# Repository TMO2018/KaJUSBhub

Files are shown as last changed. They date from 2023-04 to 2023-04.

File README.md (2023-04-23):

# KaJUSBhub
USB-Adapter zum Einbau in ein C64-Gehäuse für die C64-Tastatur und -Joysticks zum Anschluss an den MiSTer

Auf der Platine enthalten sind:

- ein USB-Adapter dür die C64-Tastatur und -9-pol. Joystcks
- der USB-Hub des MiSTers
- eine über Feinsicherungen abgesicherte Stromversorgung für den MiSter, USB-Adapter und USB-Hub

Die Spannungsversorgung erfolgt mit einem C64-Netzteil.

Rev 0.1:
Version mit einem gemeinsamen Mikrocontroller PIC18F4550 für C64-Tastatur und -Joysticks

Rev 0.2:
Version mit seperaten Mikrocontrollern PIC18F4550 für C64-Tastatur und -Joysticks

Die Firmware basiert auf dem Projekt C64 VICE front-end von Simon Inns.
https://www.waitingforfriday.com/?p=470

IMG_Rev_0 1

Rev 0.1

Hinweis: In den Schaltplänen der Versionen 0.1 und 0.2 ist der Mikrokontroller mit PIC18F4450 beschriftet. Richtig ist aber PIC18F4550. Beide Mikrokontroller sind pin-kompatibel.

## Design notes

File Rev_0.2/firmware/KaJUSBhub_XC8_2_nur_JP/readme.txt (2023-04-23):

Versionen IDE und Compiler

MBLAB X 5.15 XC8 2.05

27.03.2019 
Keymapping auf dem MISTer C64-Core angepasst

24.06.2021
MBLAB X 5.50 XC8 2.32

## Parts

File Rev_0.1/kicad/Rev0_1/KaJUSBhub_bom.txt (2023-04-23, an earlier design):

Reference, Quantity, Value, Footprint, Datasheet
C1 C2 C5 C6 ,4,"220nF","Capacitors_SMD:C_0805_HandSoldering",""
C10 C11 C13 C15 C17 C18 C19 C20 C21 C22 ,10,"10uF","Capacitors_SMD:C_0805_HandSoldering",""
C12 ,1,"0.1uF","Capacitors_SMD:C_0805_HandSoldering",""
C14 C16 ,2,"0,1uF","Capacitors_SMD:C_0805_HandSoldering",""
C3 C4 ,2,"15pF","Capacitors_SMD:C_0805_HandSoldering",""
C7 C8 ,2,"100nF","Capacitors_SMD:C_0805_HandSoldering",""
C9 ,1,"470nF","Capacitors_SMD:C_0805_HandSoldering",""
F1 ,1,"0,5A flink","Fuse_Holders_and_Fuses:Fuseholder5x20_horiz_open_inline_Type-I",""
F2 ,1,"1,0A flink","Fuse_Holders_and_Fuses:Fuseholder5x20_horiz_open_inline_Type-I",""
F3 ,1,"2,0A träge","Fuse_Holders_and_Fuses:Fuseholder5x20_horiz_open_inline_Type-I",""
J1 ,1,"DIN-7","TMO:din-7",""
J2 ,1,"Versorgung MISTer","Connectors_Molex:Molex_KK-6410-02_02x2.54mm_Straight","~"
J3 ,1,"ICSP","Pin_Headers:Pin_Header_Straight_1x06_Pitch2.54mm",""
J4 ,1,"Joystick Port 1","Connectors_DSub:DSUB-9_Male_Horizontal_Pitch2.77x2.84mm_EdgePinOffset7.70mm_Housed_MountingHolesOffset9.12mm",""
J5 ,1,"Status-LED","TMO:Pin_Header_Straight_1x03_Pitch2.54mm_long_pad",""
J6 ,1,"Joystick Port 2","Connectors_DSub:DSUB-9_Male_Horizontal_Pitch2.77x2.84mm_EdgePinOffset7.70mm_Housed_MountingHolesOffset9.12mm",""
J7 ,1,"C64 Keyboard","TMO:Pin_Header_Straight_1x20_Pitch2.54mm_long_pad",""
LED1 LED11 LED13 LED3 LED5 LED7 LED9 ,7,"green","LEDs:LED_0805_HandSoldering",""
LED15 ,1,"red","LEDs:LED_0805_HandSoldering",""
LED10 LED12 LED14 LED2 LED4 LED6 LED8 ,7,"amber","LEDs:LED_0805_HandSoldering",""
MH1 MH2 MH3 MH4 MH5 ,5,"Conn_01x01","Mounting_Holes:MountingHole_3.7mm",""
P1 ,1,"USB IN","TMO:Pin_Header_Straight_1x04_Pitch2.54mm_long_pad",""
R1 R18 R2 R3 R4 ,5,"100k","Resistors_SMD:R_0805_HandSoldering",""
R10 R11 R12 R13 R14 R15 R16 R9 ,8,"510","Resistors_SMD:R_0805_HandSoldering",""
R17 ,1,"47k","Resistors_SMD:R_0805_HandSoldering",""
R19 ,1,"2k7","Resistors_SMD:R_0805_HandSoldering",""
R6 ,1,"1k","Resistors_SMD:R_0805_HandSoldering",""
R7 ,1,"150","Resistors_SMD:R_0805_HandSoldering",""
R5 R8 ,2,"10k","Resistors_SMD:R_0805_HandSoldering",""
SW1 ,1,"DPDT_SWITCH","TMO:DPDT_SWITCH",""
U1 ,1,"PIC18F4450-IP","Housings_DIP:DIP-40_W15.24mm_Socket_LongPads",""
U2 ,1,"24C02","Housings_SOIC:SOIC-8_3.9x4.9mm_Pitch1.27mm",""
U3 ,1,"FE2.1-48","Housings_QFP:LQFP-48_7x7mm_Pitch0.5mm",""
USB1 USB2 USB3 ,3,"USB_A","Connectors:USB_A",""
USB5 USB6 ,2,"USB out","TMO:Pin_Header_Straight_1x04_Pitch2.54mm_long_pad",""
USB7 ,1,"USB out","Pin_Headers:Pin_Header_Straight_1x04_Pitch2.54mm",""
X1 ,1,"20MHz","Crystals:Crystal_SMD_5032-2pin_5.0x3.2mm_HandSoldering",""
X2 ,1,"12MHz","Crystals:Crystal_SMD_5032-2pin_5.0x3.2mm_HandSoldering",""

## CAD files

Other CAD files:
Rev_0.1/firmware/KaJUSBhub_XC8_1/KaJUSBhub.X/dist/default/production/KaJUSBhub.X.production.obj

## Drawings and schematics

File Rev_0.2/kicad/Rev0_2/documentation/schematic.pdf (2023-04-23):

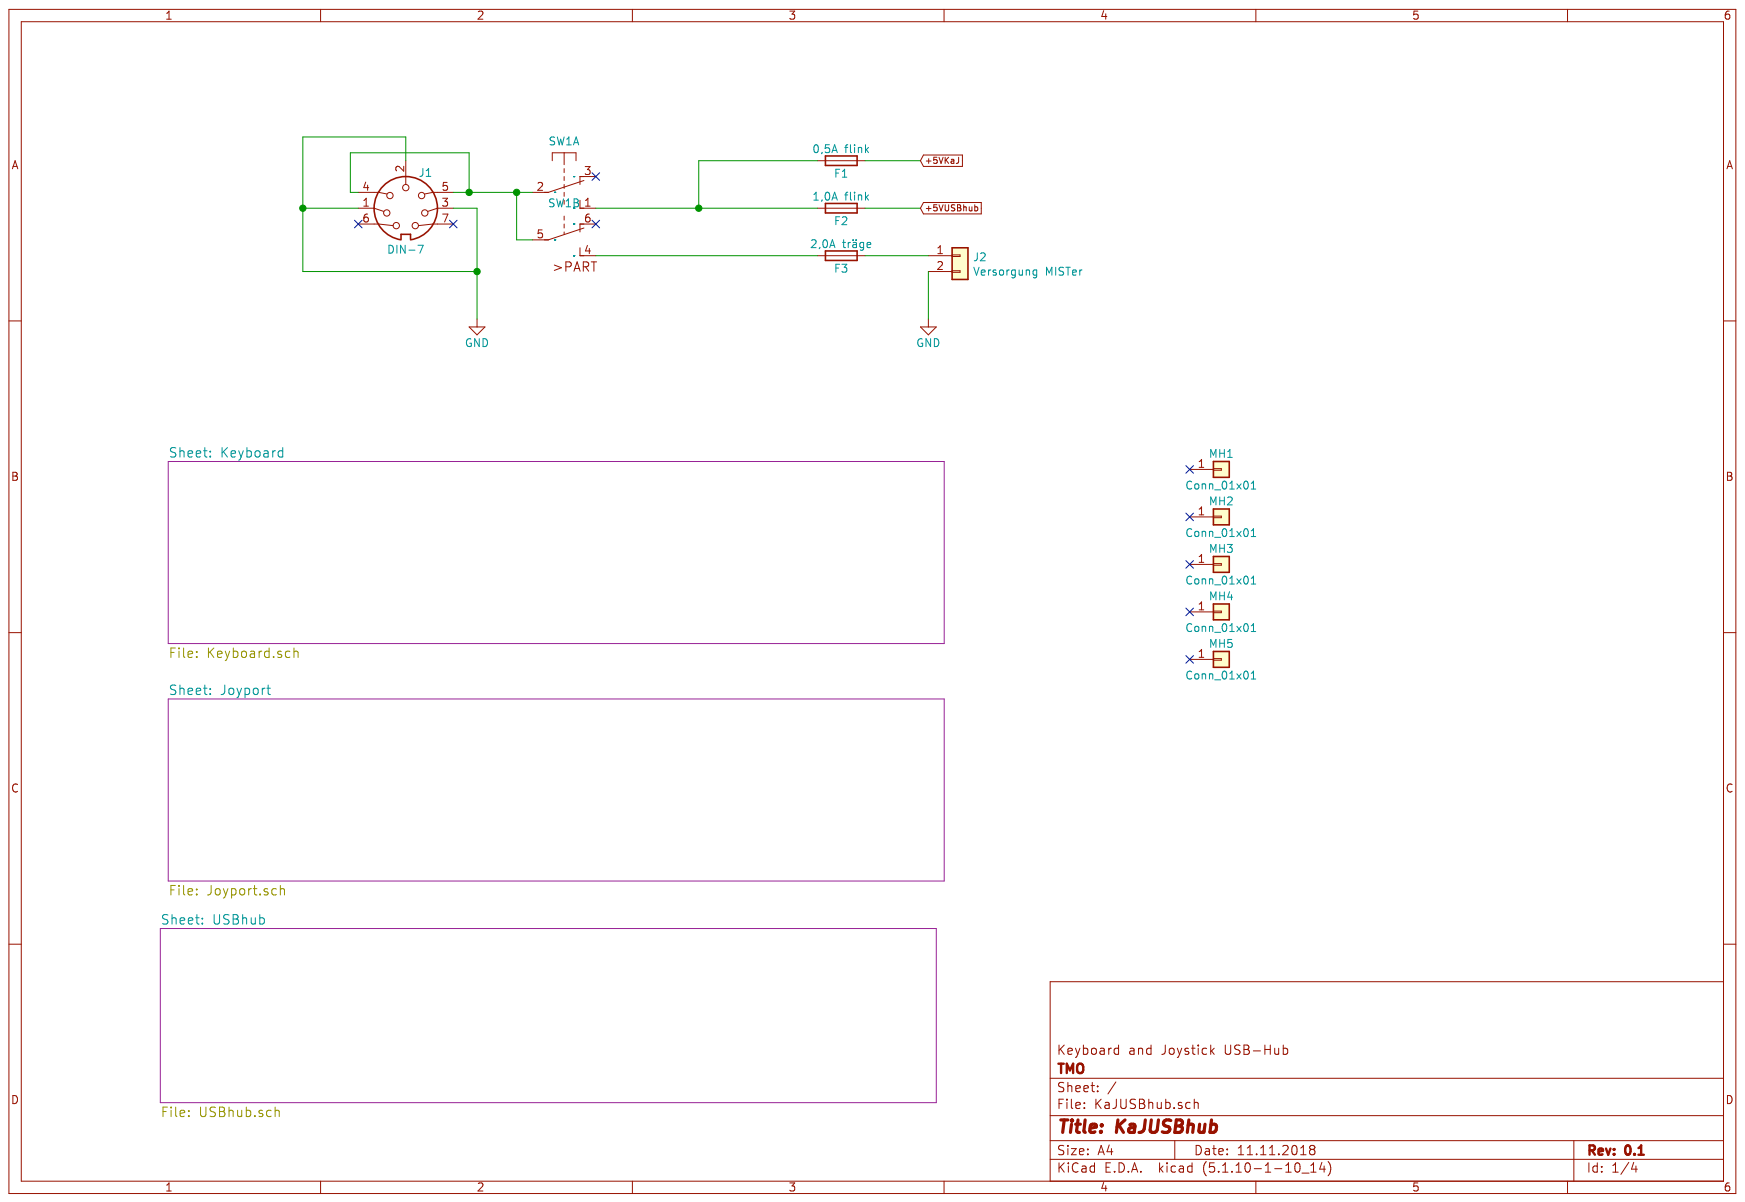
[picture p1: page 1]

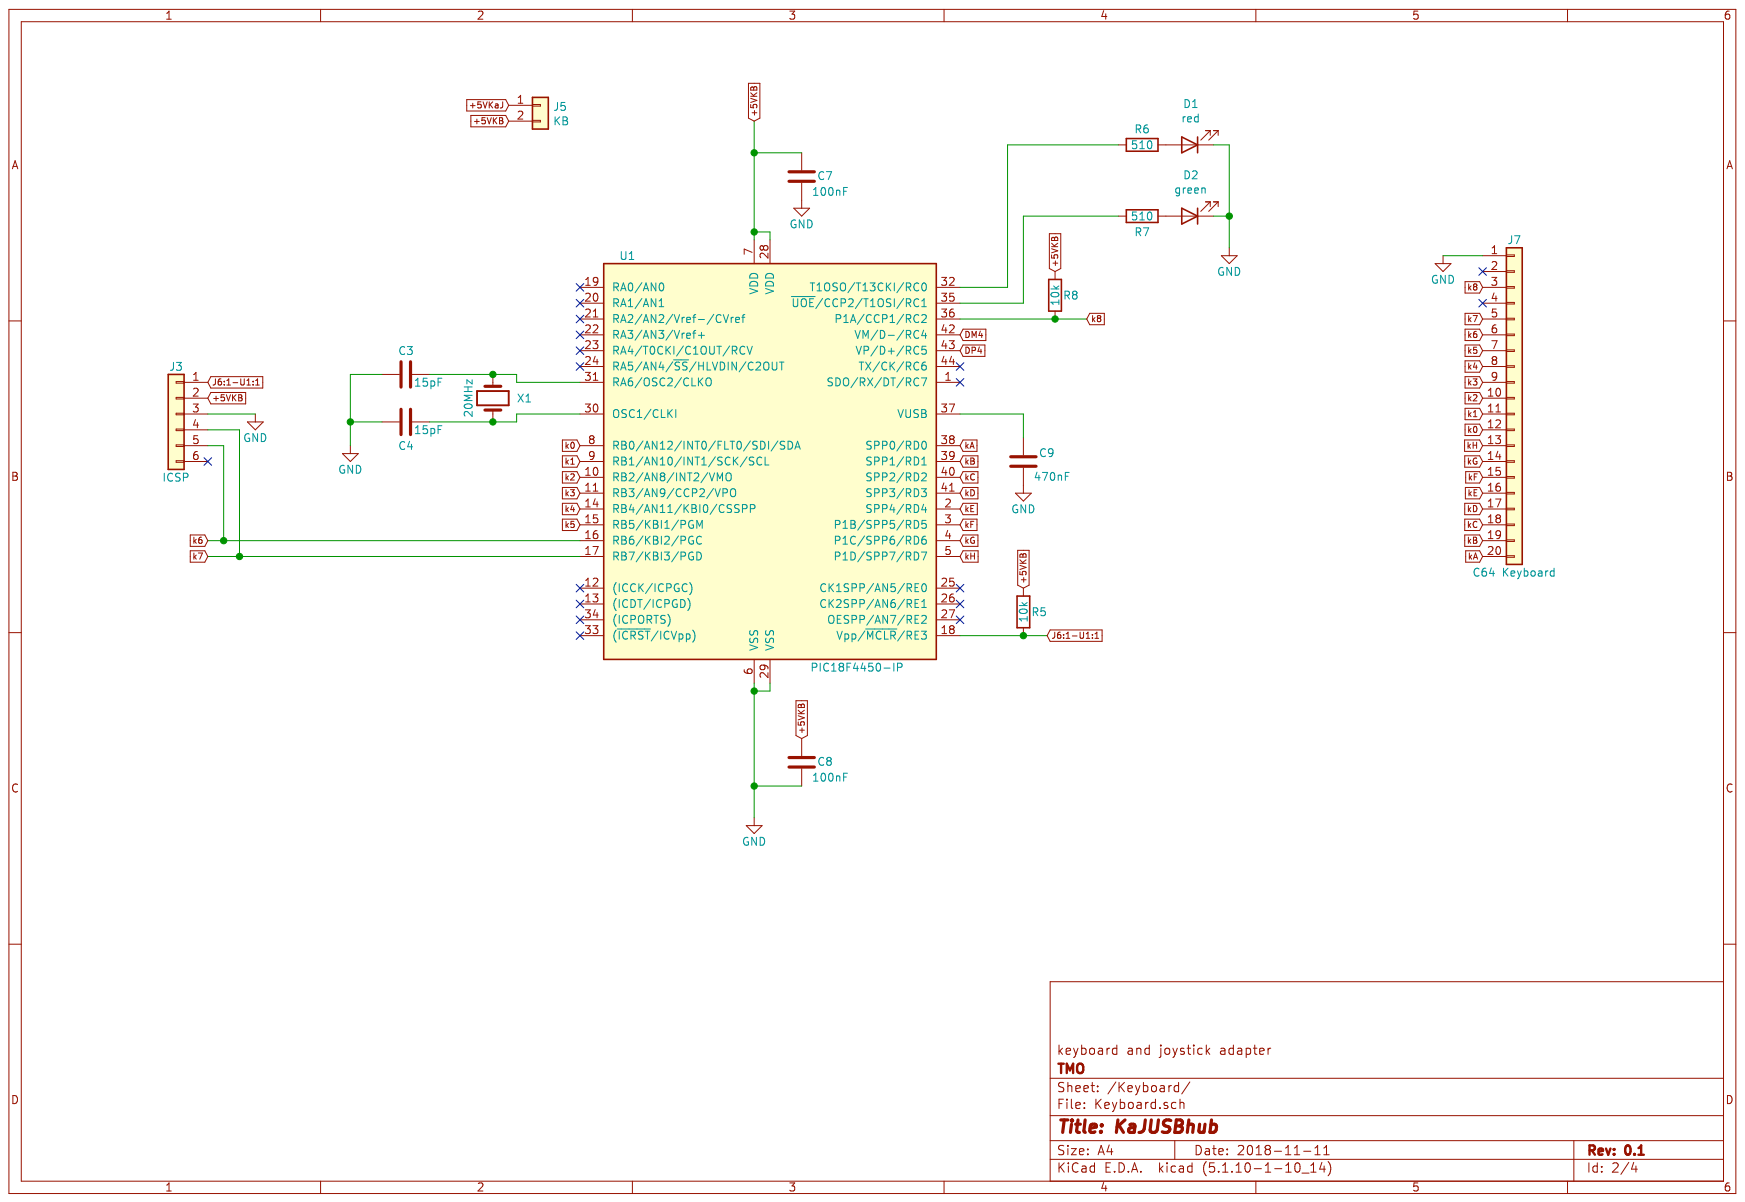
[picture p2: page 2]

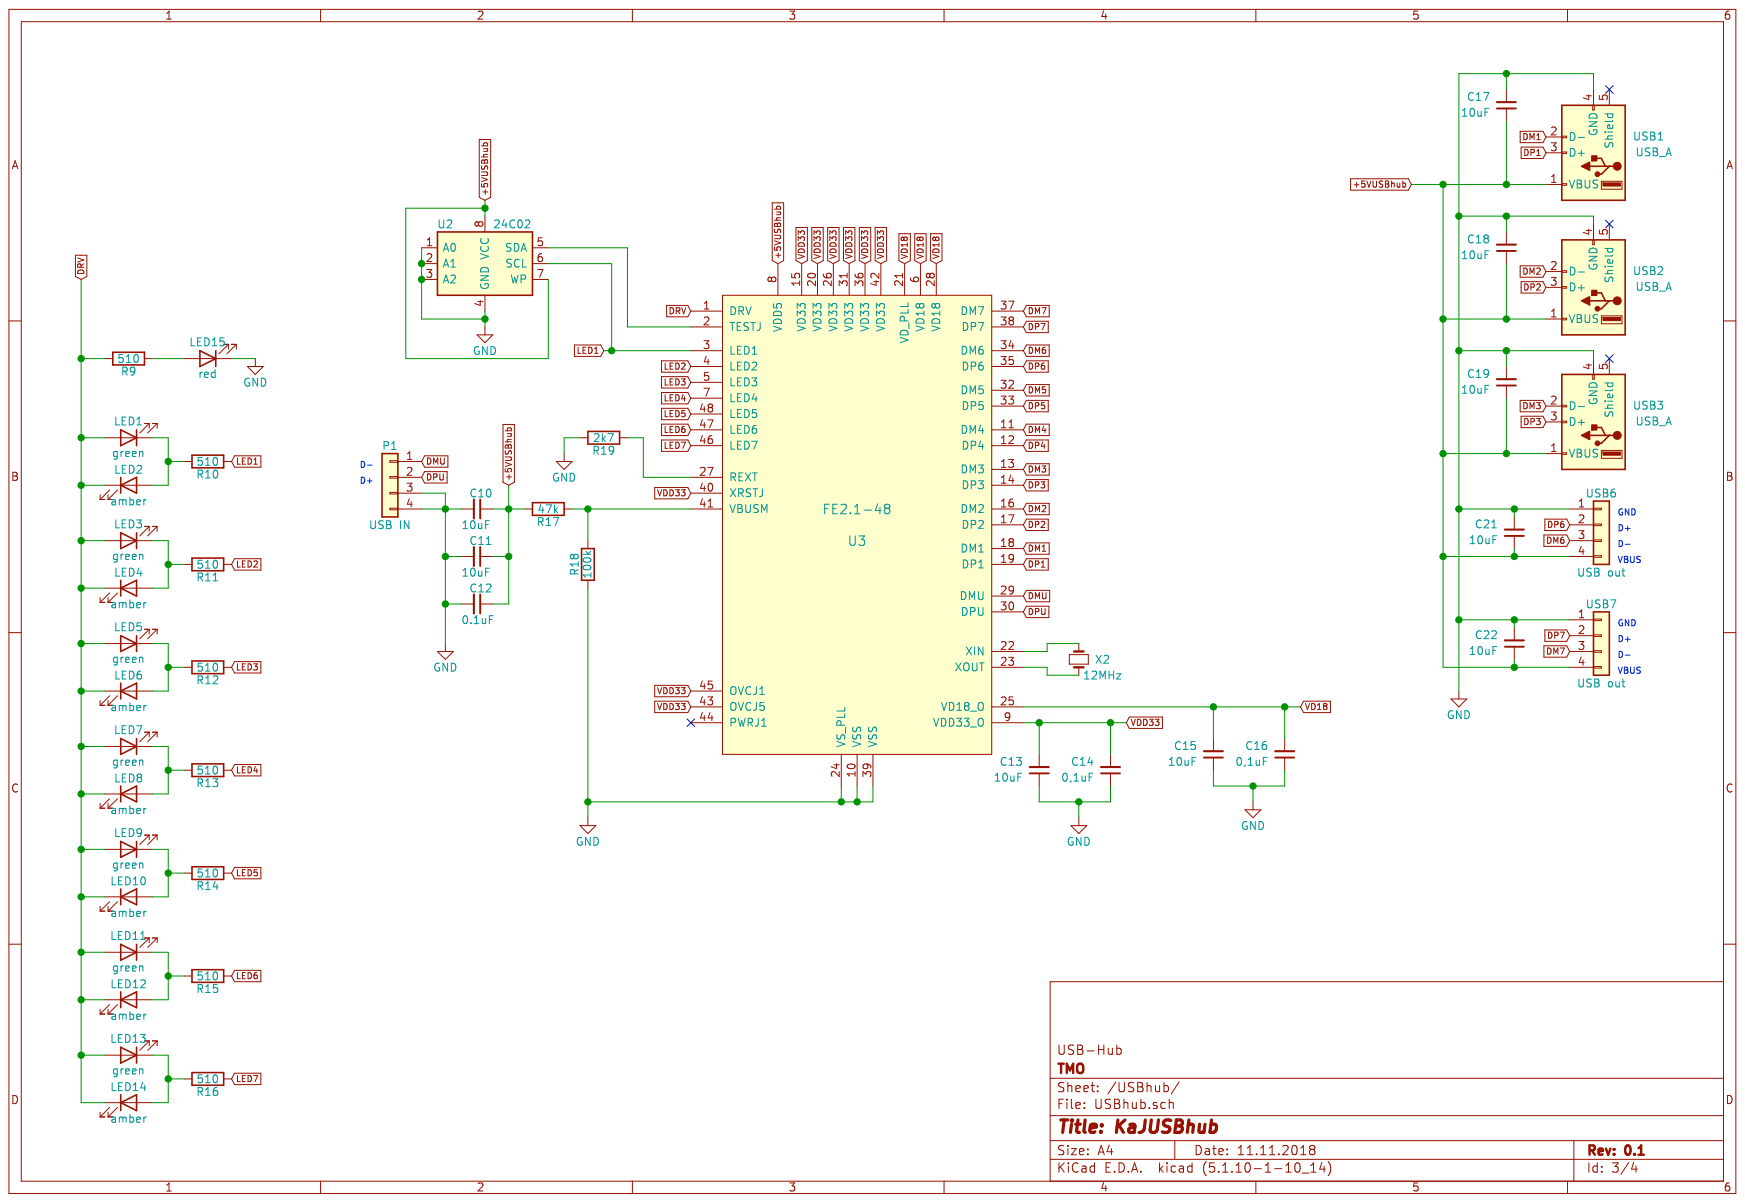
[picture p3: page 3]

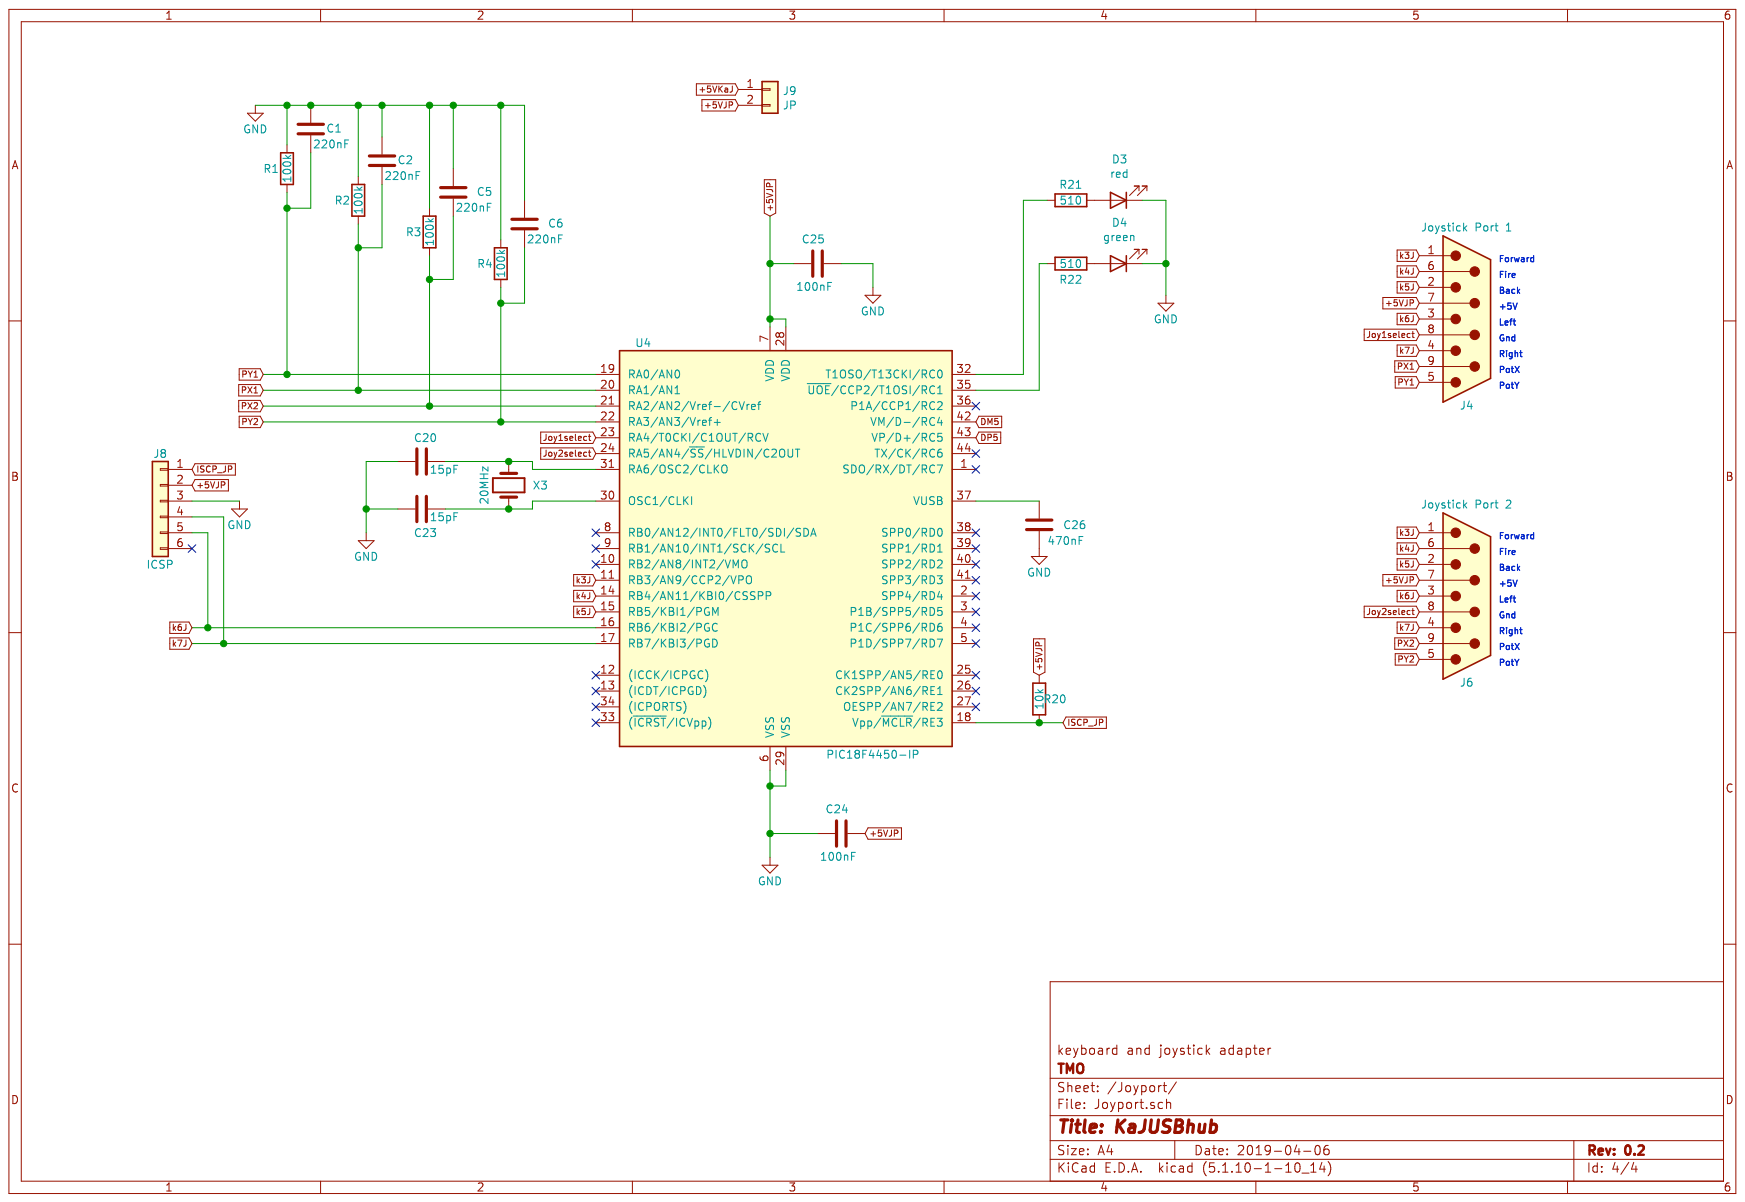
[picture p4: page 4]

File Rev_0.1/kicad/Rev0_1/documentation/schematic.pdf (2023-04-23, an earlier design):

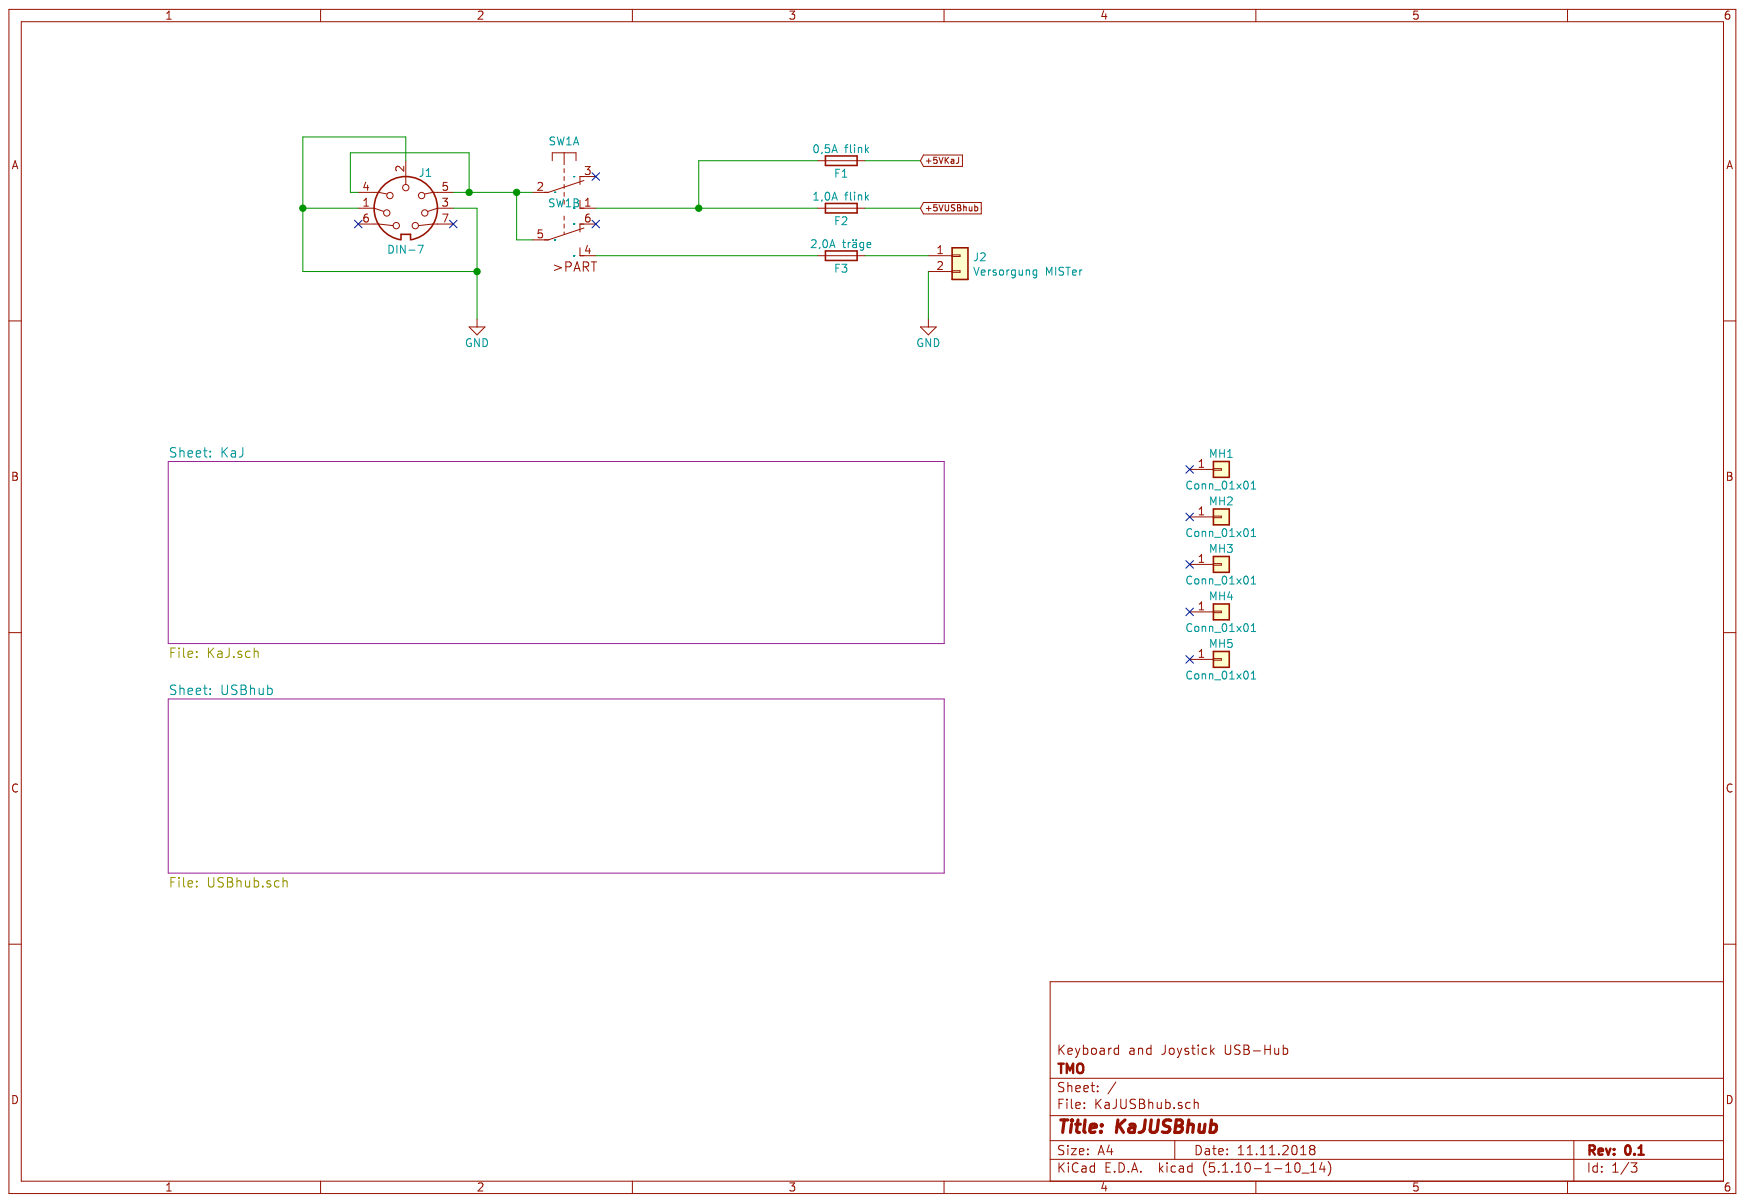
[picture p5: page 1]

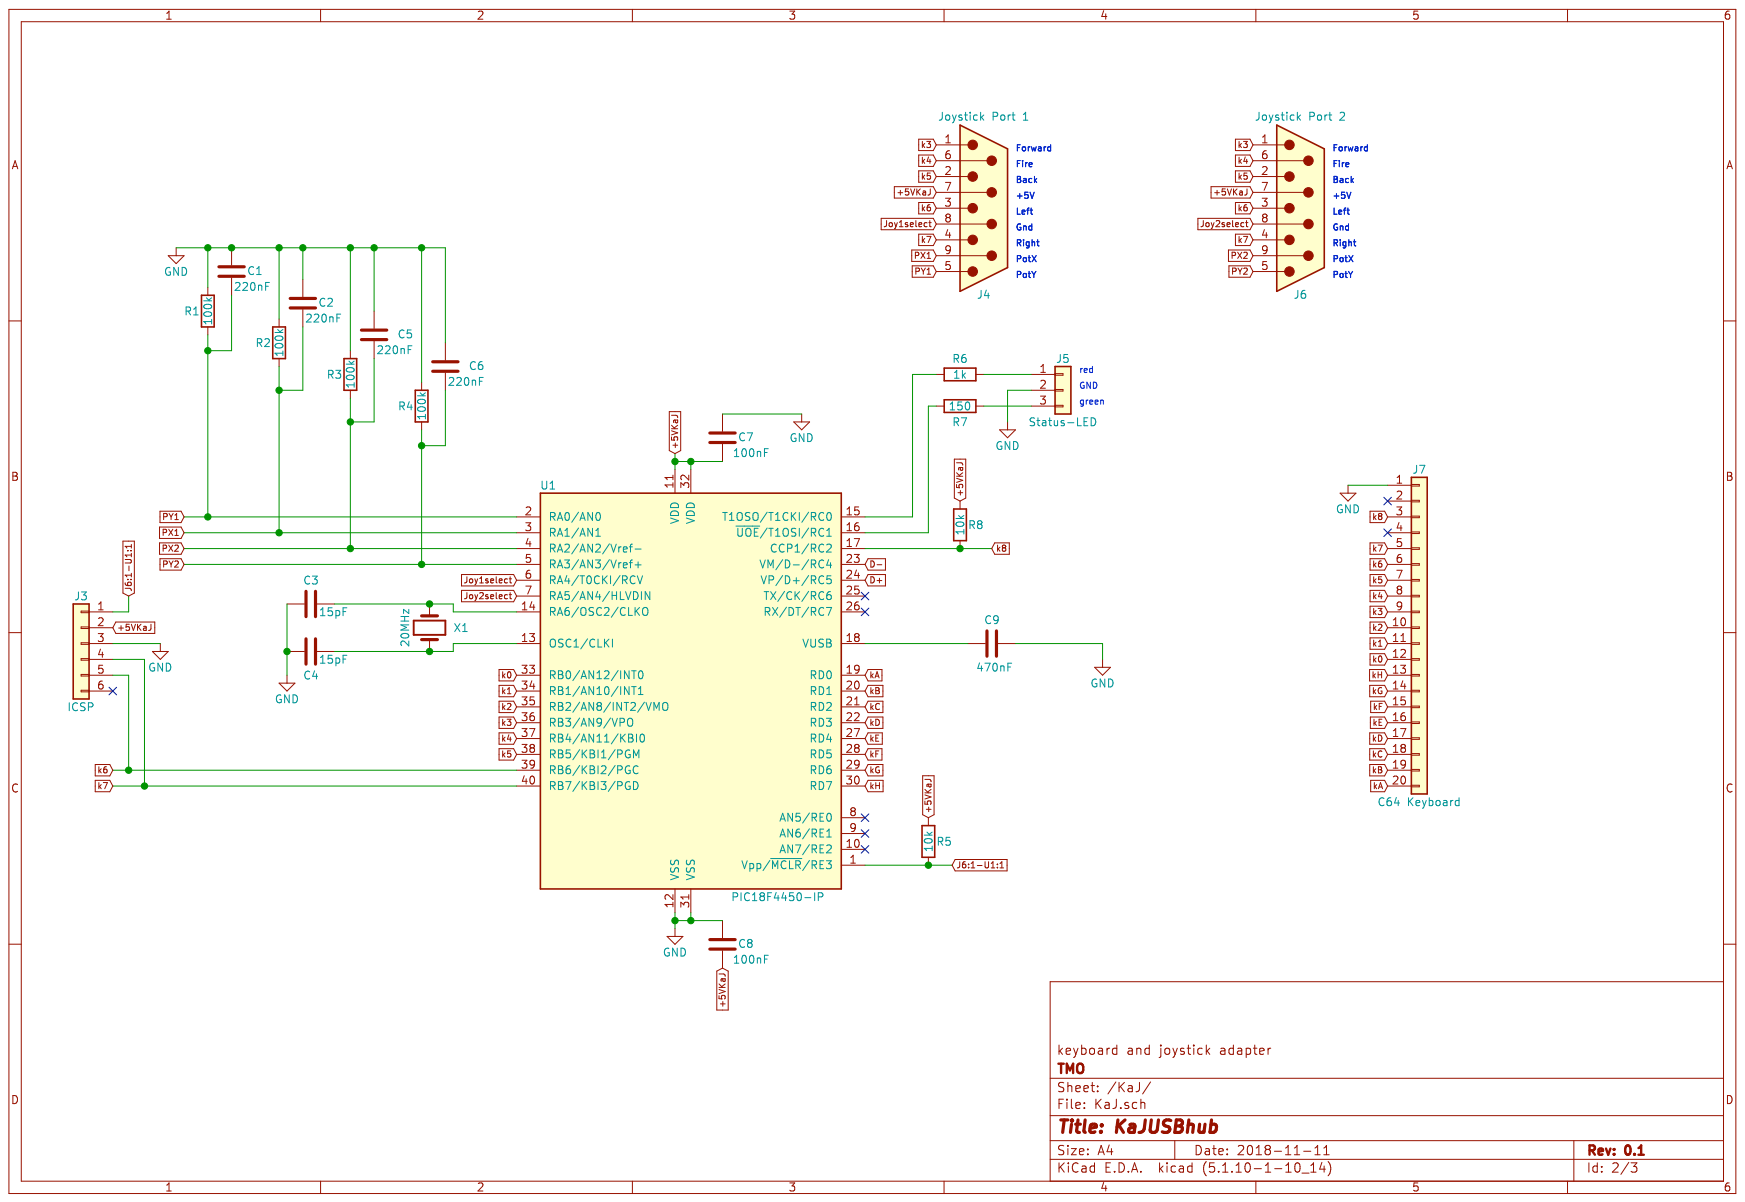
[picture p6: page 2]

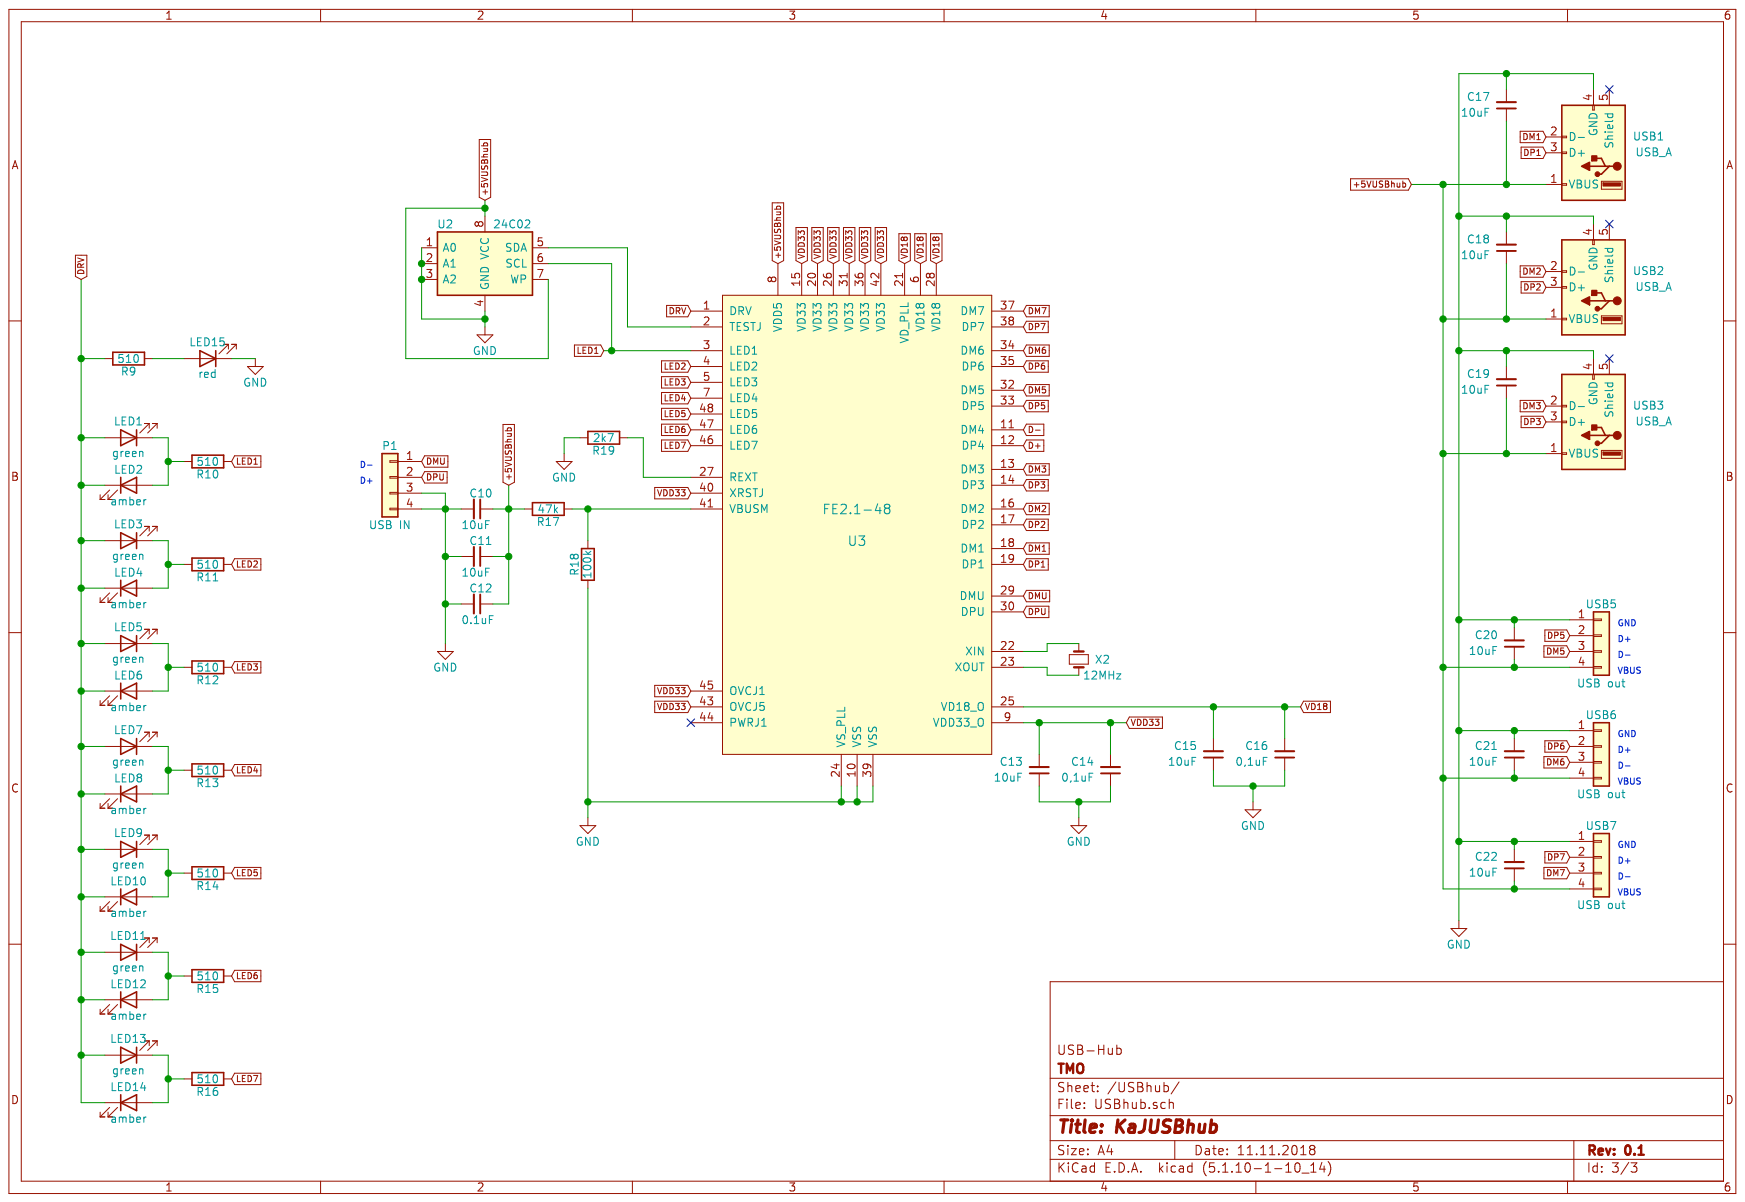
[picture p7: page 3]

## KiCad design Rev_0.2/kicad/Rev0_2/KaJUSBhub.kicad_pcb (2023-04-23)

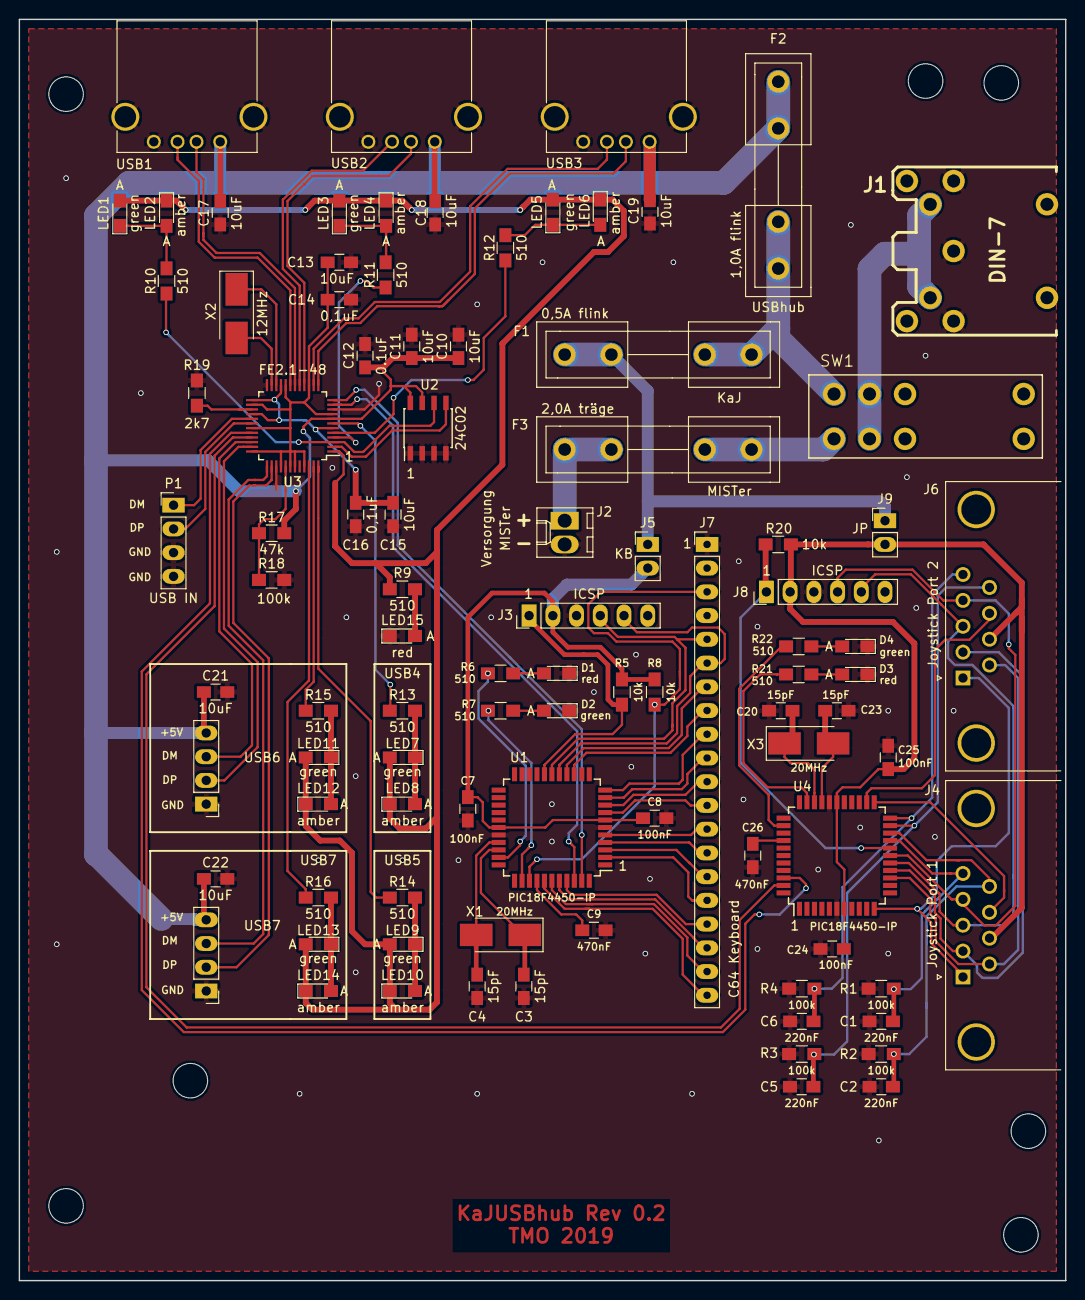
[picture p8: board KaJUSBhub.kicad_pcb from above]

Board: 2 copper layers, 112.0 x 135.0 mm, 98 parts (0 on the bottom side), 92 nets.

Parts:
C1, C2, C5, C6: 220nF; C_0805_HandSoldering
C3, C4, C20, C23: 15pF; C_0805_HandSoldering
C7, C8, C24, C25: 100nF; C_0805_HandSoldering
C9, C26: 470nF; C_0805_HandSoldering
C10, C11, C13, C15, C17, C18, C19, C21, C22: 10uF; C_0805_HandSoldering
C12: 0.1uF; C_0805_HandSoldering
C14, C16: 0,1uF; C_0805_HandSoldering
D1, D3: red; LED_0805_HandSoldering
D2, D4: green; LED_0805_HandSoldering
F1: 0,5A flink; Fuseholder5x20_horiz_open_inline_Type-I
F2: 1,0A flink; Fuseholder5x20_horiz_open_inline_Type-I
F3: 2,0A träge; Fuseholder5x20_horiz_open_inline_Type-I
J1: DIN-7; din-7
J2: Versorgung MISTer; Molex_KK-6410-02_02x2.54mm_Straight
J3, J8: ICSP; Pin_Header_Straight_1x06_Pitch2.54mm
J4: Joystick Port 1; DSUB-9_Male_Horizontal_Pitch2.77x2.84mm_EdgePinOffset7.70mm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
J5: KB; Pin_Header_Straight_1x02_Pitch2.54mm
J6: Joystick Port 2; DSUB-9_Male_Horizontal_Pitch2.77x2.84mm_EdgePinOffset7.70mm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
J7: C64 Keyboard; Pin_Header_Straight_1x20_Pitch2.54mm_long_pad
J9: JP; Pin_Header_Straight_1x02_Pitch2.54mm
LED1, LED3, LED5, LED7, LED9, LED11, LED13: green; LED_0805_HandSoldering
LED2, LED4, LED6, LED8, LED10, LED12, LED14: amber; LED_0805_HandSoldering
LED15: red; LED_0805_HandSoldering
MH1, MH2, MH3, MH4, MH5: Conn_01x01; MountingHole_3.7mm
P1: USB IN; Pin_Header_Straight_1x04_Pitch2.54mm_long_pad
R1, R2, R3, R4, R18: 100k; R_0805_HandSoldering
R5, R8, R20: 10k; R_0805_HandSoldering
R6, R7, R9, R10, R11, R12, R13, R14, R15, R16, R21, R22: 510; R_0805_HandSoldering
R17: 47k; R_0805_HandSoldering
R19: 2k7; R_0805_HandSoldering
SW1: DPDT_SWITCH
U1, U4: PIC18F4450-IP; TQFP-44_10x10mm_Pitch0.8mm
U2: 24C02; SOIC-8_3.9x4.9mm_Pitch1.27mm
U3: FE2.1-48; LQFP-48_7x7mm_Pitch0.5mm
USB1, USB2, USB3: USB_A
USB6: USB out; Pin_Header_Straight_1x04_Pitch2.54mm_long_pad
USB7: USB out; Pin_Header_Straight_1x04_Pitch2.54mm
X1, X3: 20MHz; Crystal_SMD_5032-2pin_5.0x3.2mm_HandSoldering
X2: 12MHz; Crystal_SMD_5032-2pin_5.0x3.2mm_HandSoldering

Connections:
+5VJP: C24.2, C25.1, J4.7, J6.7, J8.2, J9.2, R20.1, U4.7, U4.28
+5VKB: C7.2, C8.2, J3.2, J5.2, R5.1, R8.1, U1.7, U1.28
+5VKaJ: F1.1, J5.1, J9.1
+5VUSBhub: C10.1, C11.1, C12.1, C17.1, C18.1, C19.1, C21.1, C22.1, F2.1, R17.2, U2.7, U2.8, U3.8, USB1.1, USB2.1, USB3.1, USB6.4, USB7.4
DM1: U3.18, USB1.2
DM2: U3.16, USB2.2
DM3: U3.13, USB3.2
DM4: U1.42, U3.11
DM5: U3.32, U4.42
DM6: U3.34, USB6.3
DM7: U3.37, USB7.3
DMU: P1.1, U3.29
DP1: U3.19, USB1.3
DP2: U3.17, USB2.3
DP3: U3.14, USB3.3
DP4: U1.43, U3.12
DP5: U3.33, U4.43
DP6: U3.35, USB6.2
DP7: U3.38, USB7.2
DPU: P1.2, U3.30
DRV: LED1.2, LED2.1, LED3.2, LED4.1, LED5.2, LED6.1, LED7.2, LED8.1, LED9.2, LED10.1, LED11.2, LED12.1, LED13.2, LED14.1, R9.2, U3.1
GND: C1.2, C2.2, C3.2, C4.2, C5.2, C6.2, C7.1, C8.1, C9.1, C10.2, C11.2, C12.2, C13.1, C14.1, C15.1, C16.1, C17.2, C18.2, C19.2, C20.2, C21.2, C22.2, C23.2, C24.1, C25.2, C26.2, D1.1, D2.1, D3.1, D4.1, J1.1, J1.2, J1.3, J2.2, J3.3, J7.1, J8.3, LED15.1, P1.3, P1.4, R1.1, R2.1, R3.1, R4.1, R18.1, R19.2, U1.6, U1.29, U2.1, U2.2, U2.3, U2.4, U3.10, U3.24, U3.39, U4.6, U4.29, USB1.4, USB1.5, USB2.4, USB2.5, USB3.4, USB3.5, USB6.1, USB7.1
ISCP_JP: J8.1, R20.2, U4.18
J6:1-U1:1: J3.1, R5.2, U1.18
Joy1select: J4.8, U4.23
Joy2select: J6.8, U4.24
LED1: R10.1, U2.6, U3.3
LED2: R11.1, U3.4
LED3: R12.1, U3.5
LED4: R13.1, U3.7
LED5: R14.1, U3.48
LED6: R15.1, U3.47
LED7: R16.1, U3.46
unnamed: C3.1, U1.31, X1.1
unnamed: C4.1, U1.30, X1.2
unnamed: C9.2, U1.37
unnamed: C20.1, U4.31, X3.1
unnamed: C23.1, U4.30, X3.2
unnamed: C26.1, U4.37
unnamed: D1.2, R6.1
unnamed: D2.2, R7.1
unnamed: D3.2, R21.1
unnamed: D4.2, R22.1
unnamed: F1.2, F2.2, SW1.1
unnamed: F3.1, J2.1
unnamed: F3.2, SW1.4
unnamed: J1.4, J1.5, SW1.2, SW1.5
unnamed: LED1.1, LED2.2, R10.2
unnamed: LED3.1, LED4.2, R11.2
unnamed: LED5.1, LED6.2, R12.2
unnamed: LED7.1, LED8.2, R13.2
unnamed: LED9.1, LED10.2, R14.2
unnamed: LED11.1, LED12.2, R15.2
unnamed: LED13.1, LED14.2, R16.2
unnamed: LED15.2, R9.1
unnamed: R6.2, U1.32
unnamed: R7.2, U1.35
unnamed: R17.1, R18.2, U3.41
unnamed: R19.1, U3.27
unnamed: R21.2, U4.32
unnamed: R22.2, U4.35
unnamed: U2.5, U3.2
unnamed: U3.22, X2.1
unnamed: U3.23, X2.2
PX1: C2.1, J4.9, R2.2, U4.20
PX2: C5.1, J6.9, R3.2, U4.21
PY1: C1.1, J4.5, R1.2, U4.19
PY2: C6.1, J6.5, R4.2, U4.22
VD18: C15.2, C16.2, U3.6, U3.21, U3.25, U3.28
VDD33: C13.2, C14.2, U3.9, U3.15, U3.20, U3.26, U3.31, U3.36, U3.40, U3.42, U3.43, U3.45
k0: J7.12, U1.8
k1: J7.11, U1.9
k2: J7.10, U1.10
k3: J7.9, U1.11
k3J: J4.1, J6.1, U4.11
k4: J7.8, U1.14
k4J: J4.6, J6.6, U4.14
k5: J7.7, U1.15
k5J: J4.2, J6.2, U4.15
k6: J3.5, J7.6, U1.16
k6J: J4.3, J6.3, J8.5, U4.16
k7: J3.4, J7.5, U1.17
k7J: J4.4, J6.4, J8.4, U4.17
k8: J7.3, R8.2, U1.36
kA: J7.20, U1.38
kB: J7.19, U1.39
kC: J7.18, U1.40
kD: J7.17, U1.41
kE: J7.16, U1.2
kF: J7.15, U1.3
kG: J7.14, U1.4
kH: J7.13, U1.5

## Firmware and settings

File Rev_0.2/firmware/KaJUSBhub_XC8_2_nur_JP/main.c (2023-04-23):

/************************************************************************
	main.c

    C64 Keyboard and Joystick Adaptor
    Copyright (C) 2010 Simon Inns

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
	Email: simon.inns@gmail.com

************************************************************************/

// Revision information
//
// 20100122 : 1_0 : First public release for board version R2_2

// Global includes
#include <htc.h>

// USB stack includes
#include "USB Stack/Compiler.h"
#include "USB Stack/usb.h"
#include "USB Stack/joystick1_hid.h"
#include "USB Stack/joystick2_hid.h"
// #include "USB Stack/keyboard1_hid.h"

// Local includes
#include "hardware.h"
#include "usbram.h"
#include "joystick.h"
// #include "keyboard.h"
#include "usb_callback.h"


// PIC 18F4550 fuse configuration:
// Config word 1 (Oscillator configuration)
// 20Mhz crystal input scaled to 48Mhz and configured for USB operation
__CONFIG(1, USBPLL & IESODIS & FCMDIS & HSPLL & CPUDIV1 & PLLDIV5);
// Config word 2
__CONFIG(2, VREGEN & PWRTDIS & BOREN & BORV20 & WDTDIS & WDTPS32K);
// Config word 3
__CONFIG(3, PBDIGITAL & LPT1DIS & MCLREN);
// Config word 4
__CONFIG(4, XINSTDIS & STVREN & LVPDIS & ICPORTDIS & DEBUGDIS);
// Config word 5, 6 and 7 (protection configuration)
__CONFIG(5, UNPROTECT);
__CONFIG(6, UNPROTECT);
__CONFIG(7, UNPROTECT);

void initialise()
{
	initialiseJoysticks();
	// initialiseKeyboard();
}

void main(void)
{

	// Configure on-board ADC
	// Vss and Vdd as voltage references
	ADCON1 = 0b00001110;

	// Configure the ADC acquisition time according to the datasheet
	ADCON2 = 0b10110110; // Note: output is right justified

	// Set port directions
	TRISA = 0b00111111;
	TRISB = 0b11111111;
	TRISC = 0b01000100;
	TRISD = 0b00000000;
	TRISE = 0b00000000;

	// Clear all ports
	PORTA = 0b00000000;
	PORTB = 0b00000000;
	PORTC = 0b00000000;
	PORTD = 0b00000000;
	PORTE = 0b00000000;

	// Turn on weak pull-ups on port B
	RBPU = 0;

	// Initialise the system
	initialise();		// Initialise the hardware
	USBDeviceInit();	// Initialise the USB stack

	while(1)
	{
		// Perform the USB stack tasks
		USBDeviceTasks();

		// Show the device status, red for on and not configured
		// and green for on and configured
	    if(USBDeviceState == CONFIGURED_STATE)
	    {
			// USB is configured and ready
			LED_RED = OFF;
			LED_GREEN = ON;
		}
		else
	    {
			// USB is not configured
			LED_RED = ON;
			LED_GREEN = OFF;
		}

	    // Only process the USB tasks if we are in a configured state
	    if((USBDeviceState < CONFIGURED_STATE)||(USBSuspendControl==1))
		{
			// We do nothing when unconfigured...
		}
		else
		{
			// Read and debounce the joystick switches
			readJoystickState();

			// Read the keyboard switches
			// readKeyboardState();

			// Perform blocking on the keyboard to prevent key ghosting
			//
			// Note: if you comment this out, more keypress combinations will
			// work at once, but you will get ghost keypresses all the time...
			// keyboardBlocking();

			// Perform key debouncing
			// debounceKeyboard();
		
			// Call the joystick USB communication functions
			processJoystick_j1();
			processJoystick_j2();

			// Call the keyboard USB communication function
			// processKeyboard();
		}
	}
}

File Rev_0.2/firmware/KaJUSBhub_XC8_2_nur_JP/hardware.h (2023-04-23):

/************************************************************************
	hardware.h

    C64 Keyboard and Joystick Adaptor
    Copyright (C) 2010 Simon Inns

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
	Email: simon.inns@gmail.com

************************************************************************/

#ifndef _HARDWARE_H_
#define _HARDWARE_H_

	// Note: The hardware is using the programming pins RB6 and RB7 so
	// the device will not function correctly with the programmer connected.
	// This is to allow all 8 keyboard rows to be connected with out
	// external pull-up resistors (which only PORTB has).

	// Fosc frequency (48 Mhz)
	#define _XTAL_FREQ 48000000
	
	// Common useful definitions
	#define ON		1
	#define OFF		0
	#define	WRITE	0
	#define READ	1

	// Physical hardware port mapping
	
	// LEDs
	#define LED_RED		RC0
	#define LED_GREEN	RC1

	// C64 Keyboard (See schematic diagram for details)
	#define K0	RB0
	#define K1	RB1
	#define K2	RB2
	#define K3	RB3
	#define K4	RB4
	#define K5	RB5
	#define K6	RB6
	#define K7	RB7

	#define KA	TRISD0
	#define KB	TRISD1
	#define KC	TRISD2
	#define KD	TRISD3
	#define KE	TRISD4
	#define KF	TRISD5
	#define KG	TRISD6
	#define KH	TRISD7

	// RESTORE key
	#define KI	RC2

	// Keyboard debounce amount (higher for more)
	#define KEYBOARD_DEBOUNCE	5

	// Joysticks
	#define	JOY1_SELECT	RA4
	#define JOY2_SELECT	RA5

	#define JOY1_SELECT_TRIS TRISA4
	#define JOY2_SELECT_TRIS TRISA5

	#define JOY1_POTX	RA0
	#define JOY1_POTY	RA1
	#define JOY2_POTX	RA2
	#define JOY2_POTY	RA4

	// Joystick ports
	#define	PORT1	0
	#define PORT2	1
	
	// Joystick debounce amount (higher for more)
	#define JOYSTICK_DEBOUNCE	5
	
	// Joystick switches
	#define	JOYSTICK_FORWARD	RB3
	#define JOYSTICK_BACKWARD	RB5
	#define JOYSTICK_LEFT		RB6
	#define JOYSTICK_RIGHT		RB7
	#define JOYSTICK_FIRE		RB4

	// Joystick directions
	#define	FORWARD		0
	#define BACKWARD	1
	#define LEFT		2
	#define RIGHT		3
	#define FIRE		4

	// Joystick ADC identifiers
	#define POTX1	0
	#define POTY1	1
	#define POTX2	3
	#define POTY2	4

	// USB bus sensing defines
	#define USB_BUS_SENSE	1
	//#define USB_BUS_SENSE	RA1
	//#define USE_USB_BUS_SENSE_IO
	#define self_power 0

	// Turn on the hi-tech c18 pro porting code
	#define PICC18PORT

#endif

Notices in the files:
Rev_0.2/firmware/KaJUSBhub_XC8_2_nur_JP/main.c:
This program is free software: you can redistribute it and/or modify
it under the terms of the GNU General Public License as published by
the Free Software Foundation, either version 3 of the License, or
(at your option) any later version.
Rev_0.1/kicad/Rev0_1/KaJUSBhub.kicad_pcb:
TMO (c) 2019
